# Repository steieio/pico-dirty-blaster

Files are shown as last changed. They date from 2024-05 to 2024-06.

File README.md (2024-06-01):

# Pico Dirty Blaster
USB Blaster adapters for [pico-dirtyJtag](https://github.com/phdussud/pico-dirtyJtag)
Also supports [Drag-n-Drop FPGA programming via UF2](https://steieio.github.io/pico-dirty-blaster/uf2jbc.html)
More documentation [available here](https://steieio.github.io/pico-dirty-blaster/)
You can purchase the PCB from [OSH Park](https://oshpark.com/)
 * [Through Hole PCB design at OSH Park](https://oshpark.com/shared_projects/5RjXdQ8y)

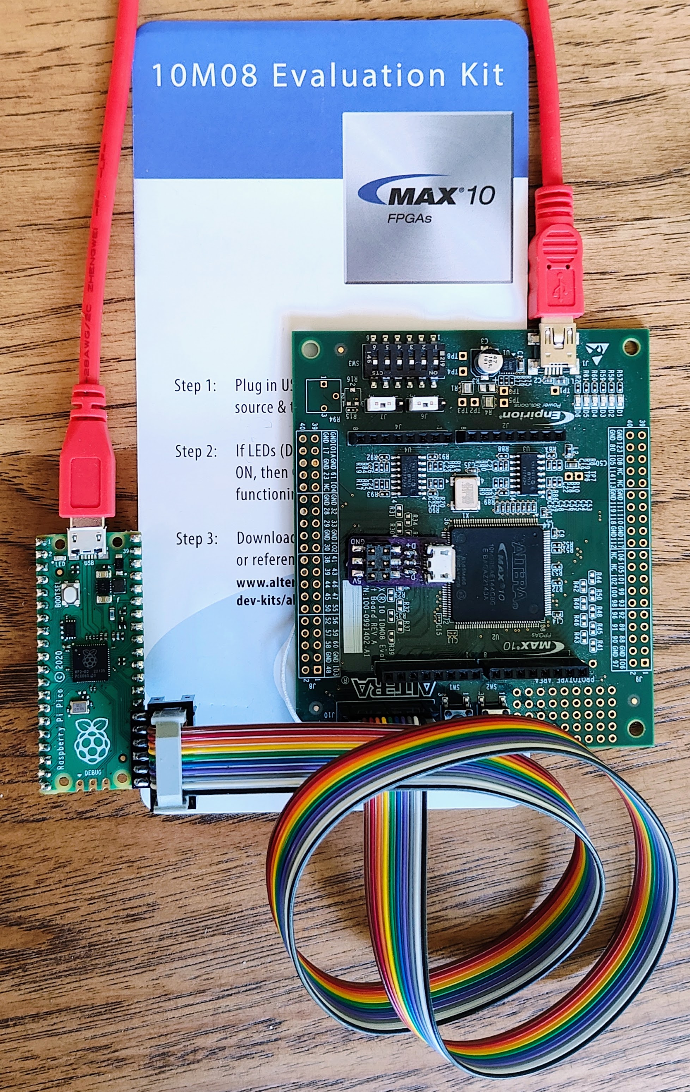
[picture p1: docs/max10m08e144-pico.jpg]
Pico Dirty Blaster connected to MAX10 evaluation kit


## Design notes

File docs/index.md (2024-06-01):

# Pico Dirty Blaster

A USB Blaster alternative based on [PICO-DIRTYJTAG](https://github.com/phdussud/pico-dirtyJtag) and [openFPGALoader](https://trabucayre.github.io/openFPGALoader/)

Pico Dirty Blaster connected to MAX10 evaluation kit

A [JBC player](./uf2jbc.md) is also available for these boards to allow programming devices from [JBC files](https://www.intel.com/content/www/us/en/programmable/quartushelp/current/index.htm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).

This project includes three PCB variants:
 * Through Hole  [Order from OSH Park](https://oshpark.com/shared_projects/5RjXdQ8y)
 * Surface Mount
 * Level Shift

## Through Hole

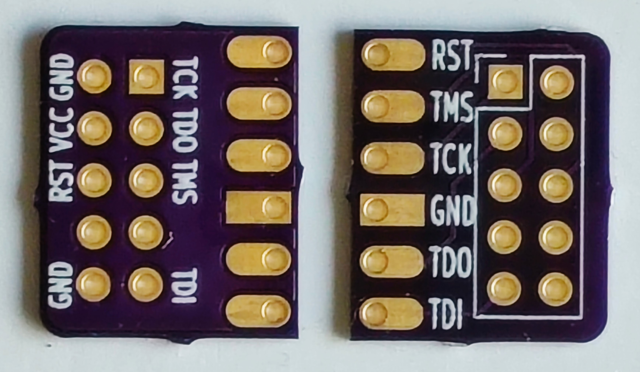
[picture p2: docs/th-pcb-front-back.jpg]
Pico Dirty Blaster through hole PCB


This variant has a single 100 mil pitch 10 pin through hole USB Blaster compatible connector on a 600 mill by 500 mil PCB.

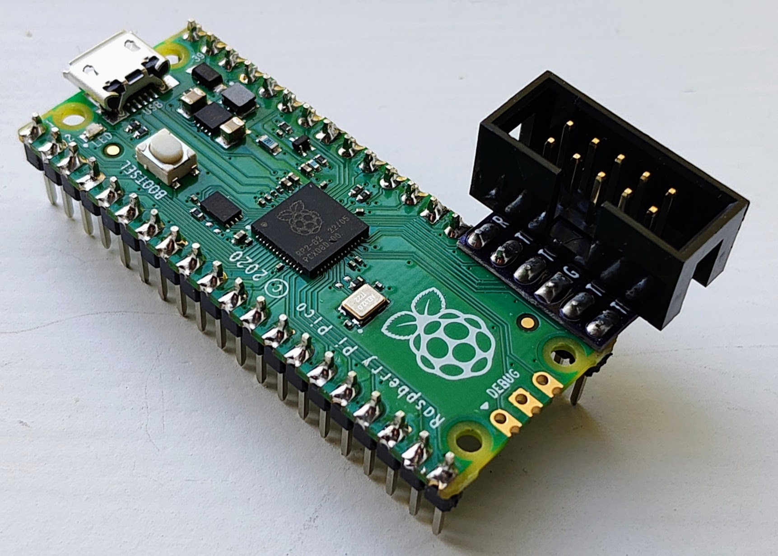
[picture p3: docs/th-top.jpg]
Pico Dirty Blaster through hole assembled top view

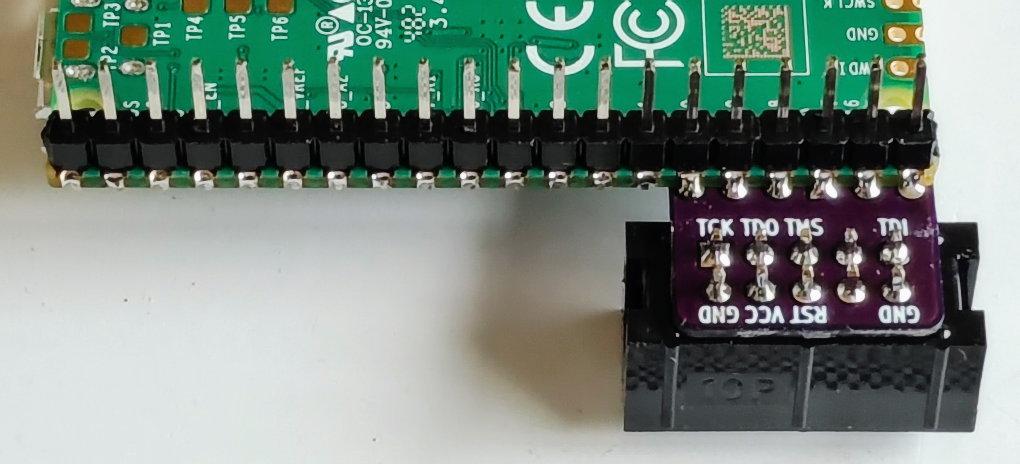
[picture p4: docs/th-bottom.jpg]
Pico Dirty Blaster through hole assembled bottom view


## Surface Mount

This variant has a 100 mil pitch 10 pin SMT USB Blaster compatible connector on top, and a 50 mil pitch 10 pin SMT Arm Cortex compatible connector on the back side.  This variant is 600 mil by 600 mil.

## Level Shift

This is a larger variant that includes level shifters to allow for different target voltages.  It has a 100 mil pitch 10 pin SMT USB Blaster compatible connector and a 50 mil pitch 10 pin SMT Arm Cortex compatible connector both on the top side.  It also has a Qwiic connector and RUN button for the PICO board.  This variant is 600 mil by 2000 mil to accomodate the additional features.

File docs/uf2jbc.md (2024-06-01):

# JBC to UF2 Utility

This tool enables Drag-n-Drop programming of an FPGA.  It converts an Altera JBC file into a UF2 file that can be loaded into a microcontroller to program an FPGA.  It takes an existing JBC player firmware file in UF2 format and adds the JBC data along with a header describing the JBC file to the player firmware.  

To use the output file, connect the Raspberry Pi Pico board to the JTAG signals on the FPGA.  The [Pico-Dirty-Blaster project](https://github.com/steieio/pico-dirty-blaster) has several adapters to assist with these connections.  Next, hold down the BOOTSEL button while plugging in the Pico board to activate the flashloader.  When the drive appears on your computer, drag-n-drop the UF2 file onto the drive to transfer the image to the Pico board.  After the image is written to the Pico board, it will reboot and run the JBC player to load the FPGA with the JBC image you provided to the script.

## Generating a JBC File

JBC is the STAPL JAM Byte Code format.  Quartus can generate these files.  In order to fit within the memory constraints of a microcontroller, compression is not supported.  Instructions for generating an uncompressed JBC file can be [found here](https://www.intel.com/content/www/us/en/support/programmable/articles/000079036.html).  

To build get an uncompressed .jbc file:

 1.  Go to Device \> Device and Pin Options \> Programming Files and select the "JEDEC STAPL Format File (.jam)" checkbox, or add ```set_global_assignment -name GENERATE_JAM_FILE ON``` to your Quartus project settings
 2.  Run ```quartus_jbcc.exe -n <filename>.jam <filename>.jbc```

## Example

```python3 uf2jbc.py -u pico-jbi.uf2 -j blinky.jbc -b 0x10020000 -a "PROGRAM" -d "MAX10 Blinky" -o max10_blinky.uf2```

## Arguments

 * -u, --uf2 \<firmware.uf2\>    JBC player firmware file in UF2 format
 * -j, --jbc \<jbc_file.uf2\>    JBC binary file of FPGA image
 * -b, --base \<JUF2 header address\>    Address of the JUF2 header
 * -a, --action \<Action String\>    String indcating action to perform \(Usually "PROGRAM")
 * -d, --description \<Description String\>    String describing the JBC image
 * -s, --speed \<TCK speed in Hz\>    TCK signal speed in Hertz \(to be implemented\)
 * -o, --output \<output.uf2\>    Output filename

## JBC Player Implementations

### pico-jbi.uf2

This is a JBC player implementation for the RP2040 based Raspberry Pi Pico board

 * JUF2 Header Address
   * 0x10020000
 * Pin Assignment
   * TCK:  18
   * TMS:  19
   * TDI:  16
   * TDO:  17

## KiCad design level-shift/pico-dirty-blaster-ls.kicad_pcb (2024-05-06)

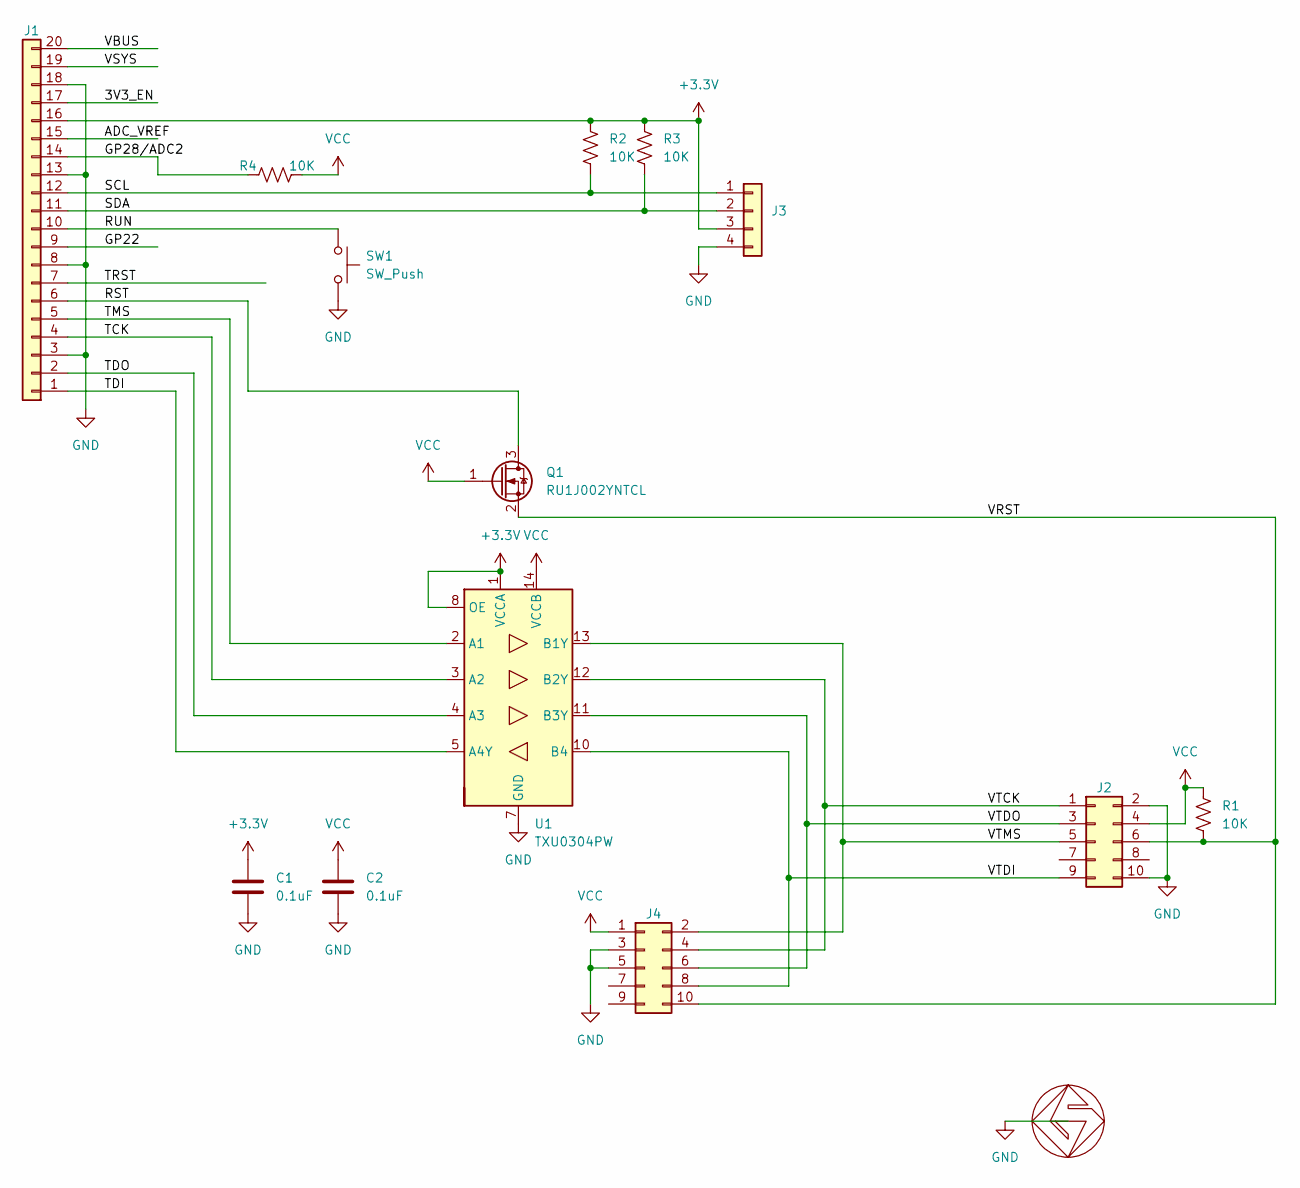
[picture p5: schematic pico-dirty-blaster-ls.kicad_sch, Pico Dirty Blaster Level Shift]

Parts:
C1, C2: 0.1uF; C_0603_1608Metric
GS1: GS_logo; gs_logo_200mil
J1: Conn_01x20; Sidecar-20
J2: Conn_02x05_Odd_Even; BHR-10-VSG-SMT_2x05_P2.54mm_Vertical_SMD
J3: Conn_01x04; JST_SH_SM04B-SRSS-TB_1x04-1MP_P1.00mm_Horizontal
J4: Conn_02x05_Odd_Even; PinHeader_2x05_P1.27mm_Vertical_SMD
Q1: RU1J002YNTCL; SOT-323_SC-70
R1, R2, R3, R4: 10K; R_0402_1005Metric
SW1: SW_Push; SW_Push_1P1T_NO_Vertical_Wuerth_434133025816
U1: TXU0304PW; TSSOP-14_4.4x5mm_P0.65mm

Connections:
+3.3V: C1.1, J1.16, J3.3, R2.1, R3.1, U1.1 (VCCA), U1.8 (OE)
/3V3_EN: J1.17
/ADC_VREF: J1.15
/GP22: J1.9
/GP28/ADC2: J1.14, R4.1
/RST: J1.6, Q1.3 (D)
/RUN: J1.10, SW1.1
/SCL: J1.12, J3.1, R2.2
/SDA: J1.11, J3.2, R3.2
/TCK: J1.4, U1.3 (A2)
/TDI: J1.1, U1.5 (A4Y)
/TDO: J1.2, U1.4 (A3)
/TMS: J1.5, U1.2 (A1)
/TRST: J1.7
/VBUS: J1.20
/VRST: J2.6, J4.10, Q1.2 (S), R1.2
/VSYS: J1.19
/VTCK: J2.1, J4.4, U1.12 (B2Y)
/VTDI: J2.9, J4.8, U1.10 (B4)
/VTDO: J2.3, J4.6, U1.11 (B3Y)
/VTMS: J2.5, J4.2, U1.13 (B1Y)
GND: C1.2, C2.2, GS1.1 (GS), J1.3, J1.8, J1.13, J1.18, J2.2, J2.10, J3.4, J4.3, J4.5, SW1.2, U1.7 (GND)
VCC: C2.1, J2.4, J4.1, Q1.1 (G), R1.1, R4.2, U1.14 (VCCB)

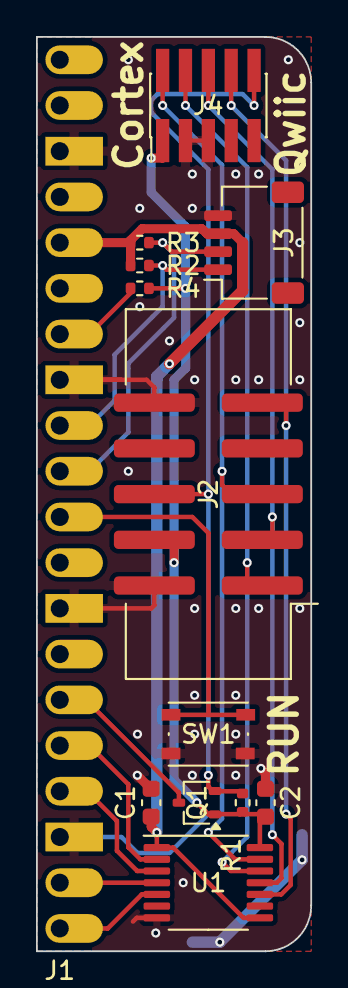
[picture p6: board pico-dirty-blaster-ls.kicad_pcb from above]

Board: 2 copper layers, 15.2 x 50.8 mm, 14 parts (1 on the bottom side), 17 nets.

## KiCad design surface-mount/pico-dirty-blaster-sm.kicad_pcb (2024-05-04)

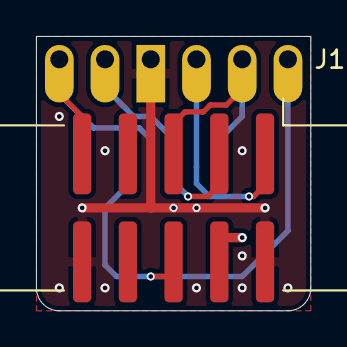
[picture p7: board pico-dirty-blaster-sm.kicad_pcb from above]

Board: 2 copper layers, 15.2 x 15.2 mm, 3 parts (1 on the bottom side), 7 nets.

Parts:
J1: Conn_01x06; Sidecar-6
J2: Conn_02x05_Counter_Clockwise; PinHeader_2x05_P1.27mm_Vertical_SMD
J3: Conn_02x05_Counter_Clockwise; BHR-10-VSG-SMT_2x05_P2.54mm_Vertical_SMD

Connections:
/J_GND: J1.4, J2.3, J2.5, J3.2, J3.10
/J_RST: J1.1, J2.10, J3.6
/J_TCK: J1.3, J2.4, J3.1
/J_TDI: J1.6, J2.8, J3.9
/J_TDO: J1.5, J2.6, J3.3
/J_TMS: J1.2, J2.2, J3.5
/J_VCC: J2.1, J3.4

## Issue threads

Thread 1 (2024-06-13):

flash does not work on MAX10 10M40SCE144C8G

xeno27, 2024-06-13:
i follow your instructions to create an uf2 file and flash it.
But the RP2040 is not flashing the FPGA ( the connections is right, i test it with openFPGALoader ).

JBC:
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

generate uf2:
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

openFPGALoader:
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

I dont find any informations about the implementation of pico-jbi.uf2 ? can you share the src ?

xeno27, 2024-06-13:
Hi i check the Loader to by the MAX10 Dev kit -> https://www.intel.com/content/www/us/en/products/details/fpga/development-kits/max/10m50.html

and add the src of an simple blink thing (it works by flashing with the USB-Blaster_ii) but the RPI is not flashing the Dev Kit.. here is the output :

JBC:
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

UF2:
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

the Quartus Project is attached (as archiv..) -> Quartus 23.01std.0 Build 991 on Ubuntu

[files.zip](https://github.com/user-attachments/files/15822188/files.zip)

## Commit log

2024-05-01 initial rev 0.1 commit
    [pico-dirty-blaster-ls.kicad_pcb, pico-dirty-blaster-ls.kicad_sch, pico-dirty-blaster-sm.kicad_pcb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]
2024-05-04 changed reset level shift to pass FET
    [pico-dirty-blaster-ls.kicad_pcb, pico-dirty-blaster-ls.kicad_sch]
2024-05-04 connected vcc on SM, 0402 R on LS
    [pico-dirty-blaster-ls.kicad_pcb, pico-dirty-blaster-ls.kicad_sch, pico-dirty-blaster-sm.kicad_pcb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]
2024-05-06 fixed part number on level shifter
    [pico-dirty-blaster-ls.kicad_pcb, pico-dirty-blaster-ls.kicad_sch]
2024-05-31 added working pico-jbi.uf2 and uf2jbc.py pair
